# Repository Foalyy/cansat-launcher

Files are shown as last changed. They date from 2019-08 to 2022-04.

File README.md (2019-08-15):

# cansat-launcher



This repository provides the documentation (in French) and the CAD files.

Related repositories :
- Kicad project : https://github.com/Foalyy/cansat-launcher-kicad
- Main board firmware : https://github.com/Foalyy/cansat-launcher-firmware
- Remote control firmware : https://github.com/Foalyy/cansat-launcher-firmware-remote

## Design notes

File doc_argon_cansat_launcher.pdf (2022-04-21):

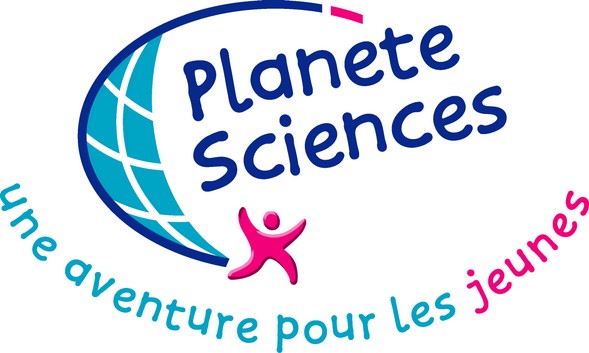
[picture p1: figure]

# Largueurs CanSat

# Argon

## Documentation

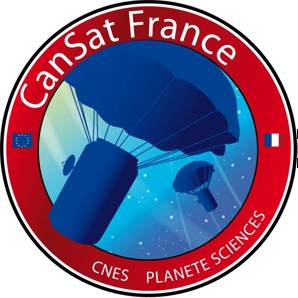
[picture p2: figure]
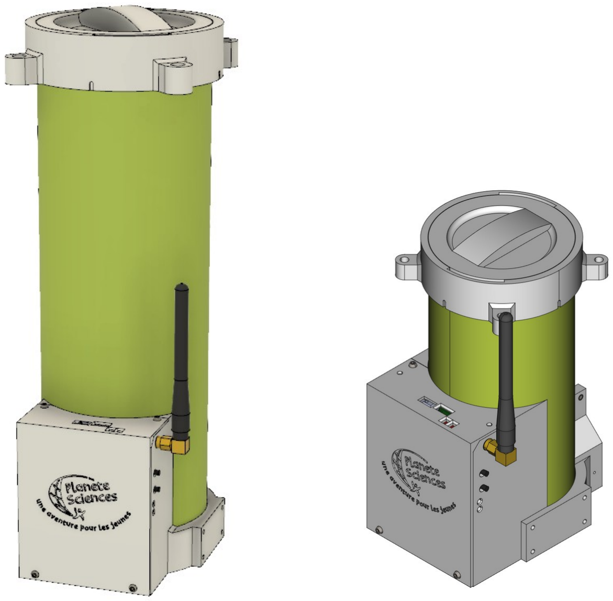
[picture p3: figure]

### Table des matières

## 1 – Manuel utilisateur

### 1.1 – Informations générales

Les largueurs existent en deux versions : la version originale « 1L » et la version « mini ».

Pour chaque version, trois largueurs sont disponibles, chacun ayant un numéro et une

couleur :

- 1 : vert
- 2 : rouge
- 3 : jaune

Deux télécommandes identiques permettent de commander à distance l’ouverture et la

fermeture (ou plus précisément, le verrouillage) de la trappe, et de recevoir des données

de télémétrie, en particulier l’altitude du largueur.

Dimensions de la version 1L :

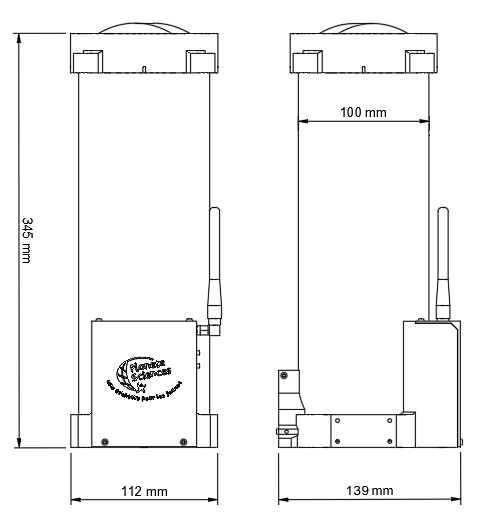
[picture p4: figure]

Masse à vide : environ 600g.

Dimensions de la version Mini :

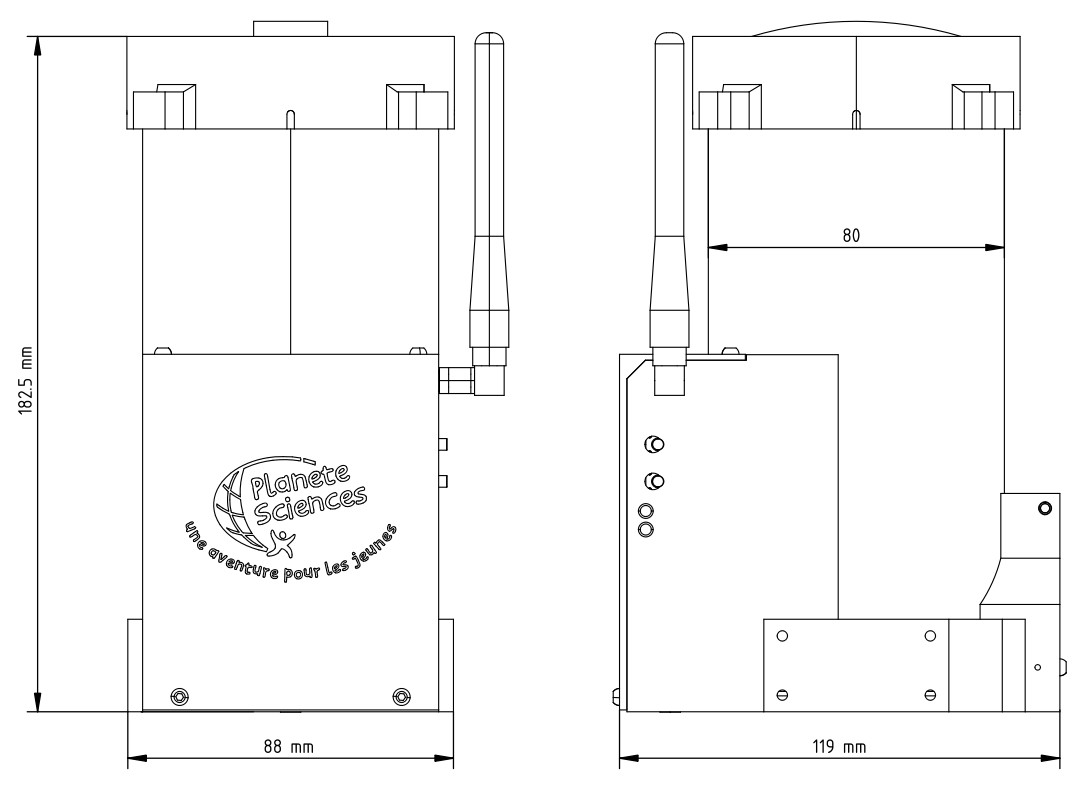
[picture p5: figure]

Masse à vide : environ 400g.

### 1.2 – Contenu des caisses

# Largueurs 1L

Deux caisses contiennent les largueurs et leurs accessoires.

La première caisse contient :

- Un largeur
- Les télécommandes
- La trousse d’accessoires contenant :
- Les trois antennes des largueurs
- Un chargeur secteur USB 3-ports
- Trois cables micro-USB
- Trois clés hexagonales 1.5mm
- Trois boîtes de rangement de batteries contenant chacun une batterie de

rechange (la deuxième batterie de chaque boîte restant dans le largueur)

- Quelques mousquetons de rechange
- Une copie de cette documentation

La deuxième caisse contient :

- Les deux autres largueurs

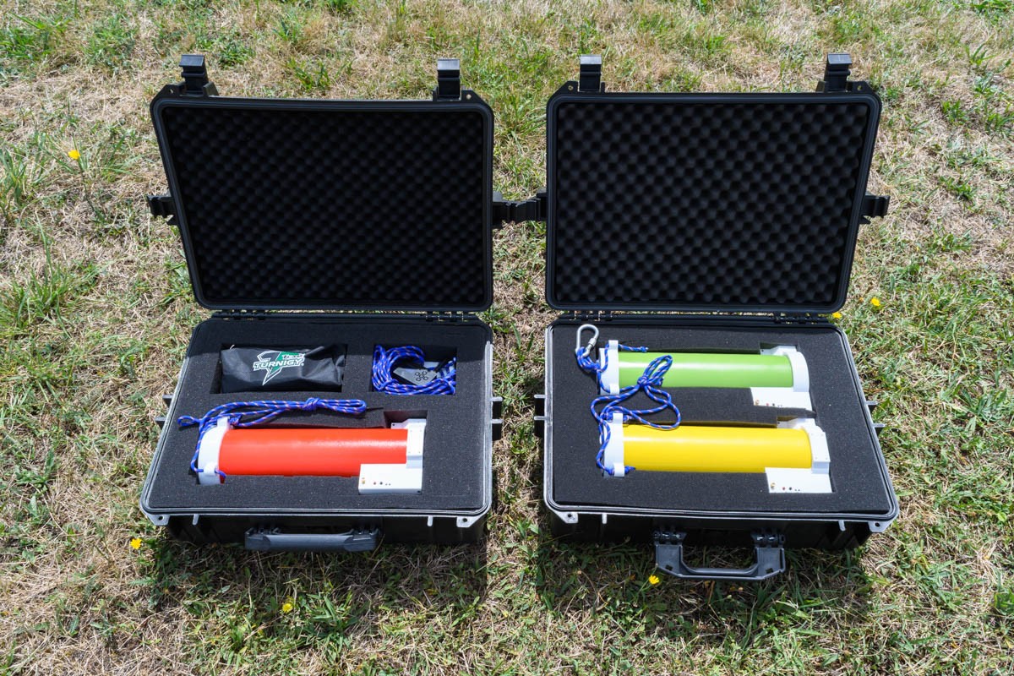
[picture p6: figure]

# Mini-largueurs

Les mini-largueurs sont stockés de manière similaire dans une unique caisse.

### 1.3 – Préparation en début de campagne

Pour chaque largueur :

1. Visser son antenne
2. Allumer le largueur et vérifier son fonctionnement manuel en testant le

mécanisme d’ouverture/fermeture à l’aide des boutons sur le côté. S’il ne s’allume

pas, la batterie doit être vide : brancher un cable USB pour l’allumer.

3. Enclencher le ressort :
1. Ouvrir la trappe avec le bouton noir

2. Dévisser la vis noire sous la charnière de la trappe à l’aide de l’une des clés

hexagonales dans la trousse à accessoires (voir photos plus bas)

3. Faire passer la boucle du ressort dans la vis puis la revisser
4. Refermer la trappe et la verrouiller avec le bouton rouge
5. Vérifier le bon fonctionnement du largueur à l’aide d’une télécommande

(ouverture, fermeture, télémétrie)

6. Recharger le largueur (prévoir environ 6 heures si la batterie est déchargée). Le

largueur doit être allumé pour pouvoir être rechargé.

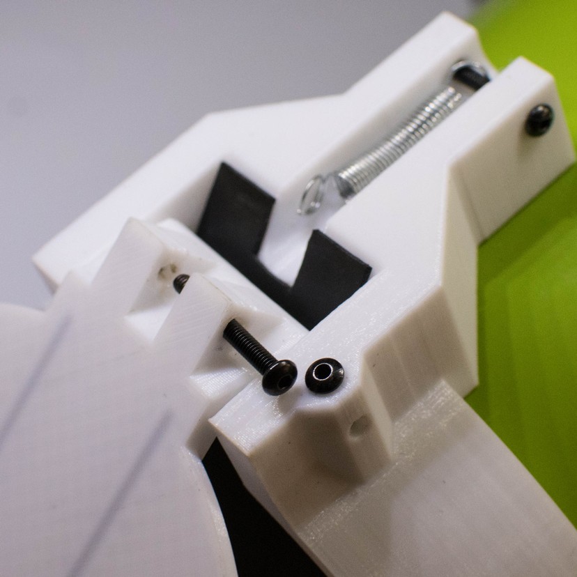
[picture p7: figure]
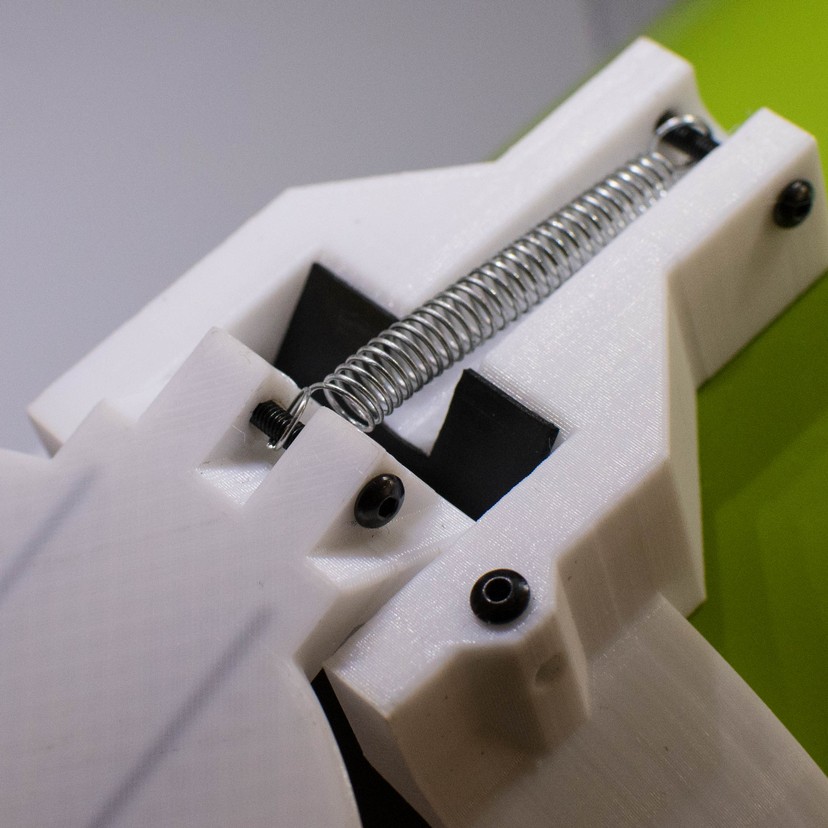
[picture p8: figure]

### 1.4 – Rangement en fin de campagne

Pour chaque largueur :

1. Regarder la charge de la batterie à l’aide d’une télécommande. Si la charge est

inférieure à 50 %, recharger le largueur jusqu’à environ 50 % (il n’est pas conseillé

de stocker la batterie pendant une longue durée complètement vide ni à pleine

charge).

2. Désenclencher le ressort de la trappe en suivant la même procédure que pour la

préparation en début de campagne (voir photos dans la section précédente) :

1. Allumer le largueur et ouvrir la trappe à l’aide du bouton
2. Dévisser la vis du bas pour dégager la boucle du ressort
3. Revisser la vis
4. Fermer et verrouiller la trappe à l’aide du bouton rouge
3. Dévisser l’antenne et la ranger dans la trousse d’accessoires
4. Ranger le largueur dans la caisse

Avant de fermer les caisses, vérifier l’inventaire (notamment de la trousse d’accessoires)

à l’aide de la liste à la section 1.2.

## 2 – Manuel technique

Ce chapitre détaille la conception du largueur et a pour but de servir de référence pour

comprendre, réparer ou construire de nouveaux largueurs.

Les fichiers STEP/STL et Gcode des pièces fabriquées par impression 3D, les plans des

cartes électroniques, ainsi que les codes sources des firmwares embarqués dans les

largueurs et les télécommandes, sont disponibles sous licence GPL sur Github :

https://github.com/Foalyy/cansat-launcher

Un build log est également disponible :

https://silica.io/argon-remote-controlled-launchers-for-the-cansat-competition/

### 2.1 – Mécanique

2.1.1 – Construction générale

Les largueurs sont construits sur la base d’un tube PVC standard du commerce, de

pièces fabriquées par impression 3D, et de divers composants dont la liste est détaillée

plus loin. Les images montrent les largueurs 1L ; la construction des mini-largueurs est

similaire, à l’exception du tube PVC qui est de diamètre 80mm (100mm pour les

largueurs 1L) et des pièces imprimées 3D dont la géométrie est adaptée en

conséquence. Les fichiers 3D des deux versions sont disponibles sur GitHub.

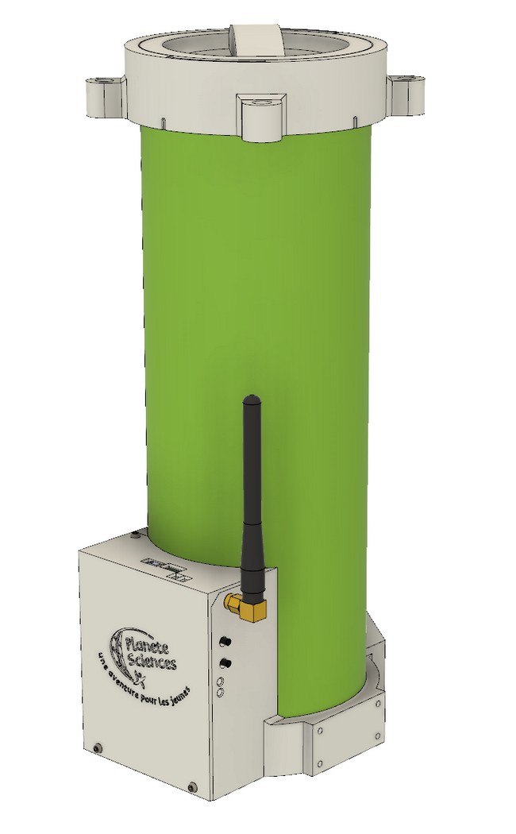
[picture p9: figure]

2.1.2 – Impression 3D

Toutes les pièces sont imprimées avec du filament Polymaker PC-Max blanc sur une

Ultimaker 2+ avec Simplify3D. Le choix s’est porté sur le polycarbonate pour sa

robustesse et sa haute tenue en température afin qu’il garde sa rigidité même pendant

de longues heures en plein soleil.

Les anneaux haut et bas sont ajustés pour rentrer « en force » autour du tube. Si besoin,

ils peuvent être collés. Il n’a pas été prévu de vis afin de laisser l’intérieur du tube

complètement lisse et éviter les risques d’accrochage des parachutes des CanSats.

Les autres pièces sont fixées à l’aide de vis et d’inserts M2.5 mis en place à chaud avec

un fer à souder.

De chaque côté du largueur, une plaque et 4 inserts permettent de fixer des

accessoires : caméra, capteurs annexes, …

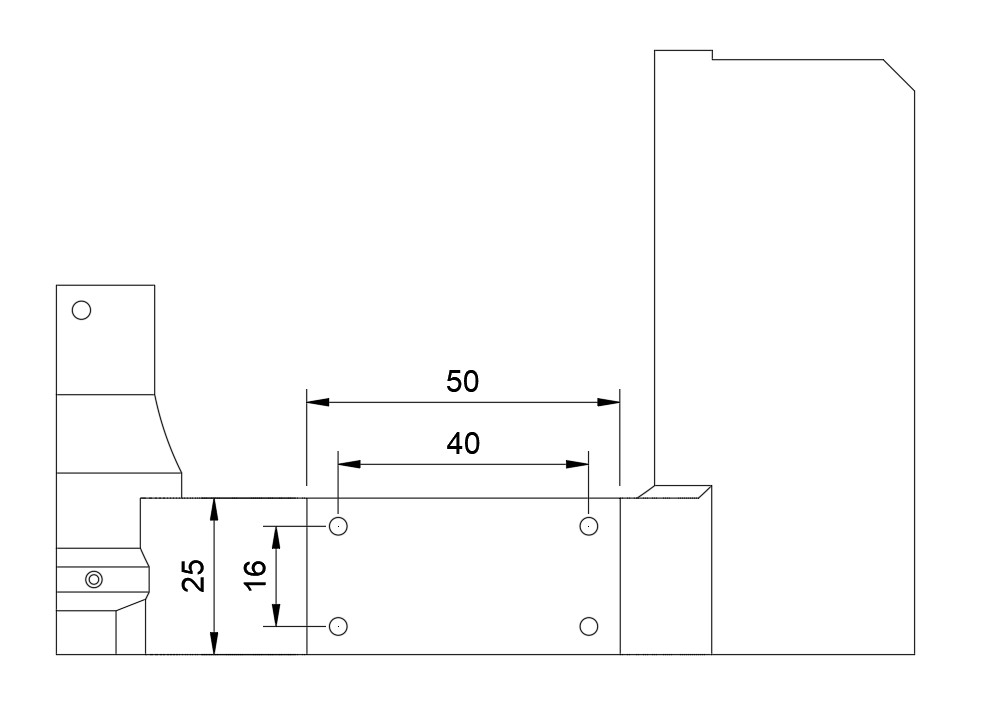
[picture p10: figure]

Caractéristiques principales du profil d’impression utilisé :

- hauteur de couche : 0.2mm
- nombre de couches externes : 2 ou 3 suivant les pièces
- remplissage : 15 à 25 % suivant les pièces
- température : extrudeur 265°C, plateau 115°C
- ventilateurs : 80 %
- vitesse : 2000mm/min
- enceinte d’impression fermée par un drap

Liste des pièces :

- Anneau bas : pièce principale intégrant le bloc électronique (dont servo et

batterie) et la charnière de la trappe. Impression avec 3 couches pour favoriser la

solidité de la pièce et la tenue des inserts. Nécessite des supports.

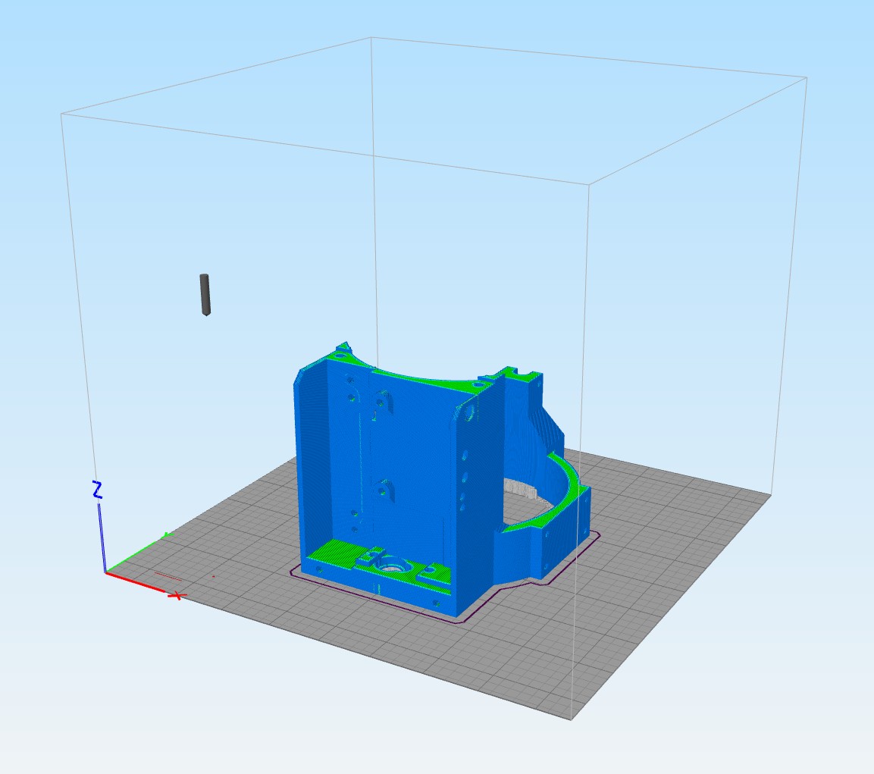
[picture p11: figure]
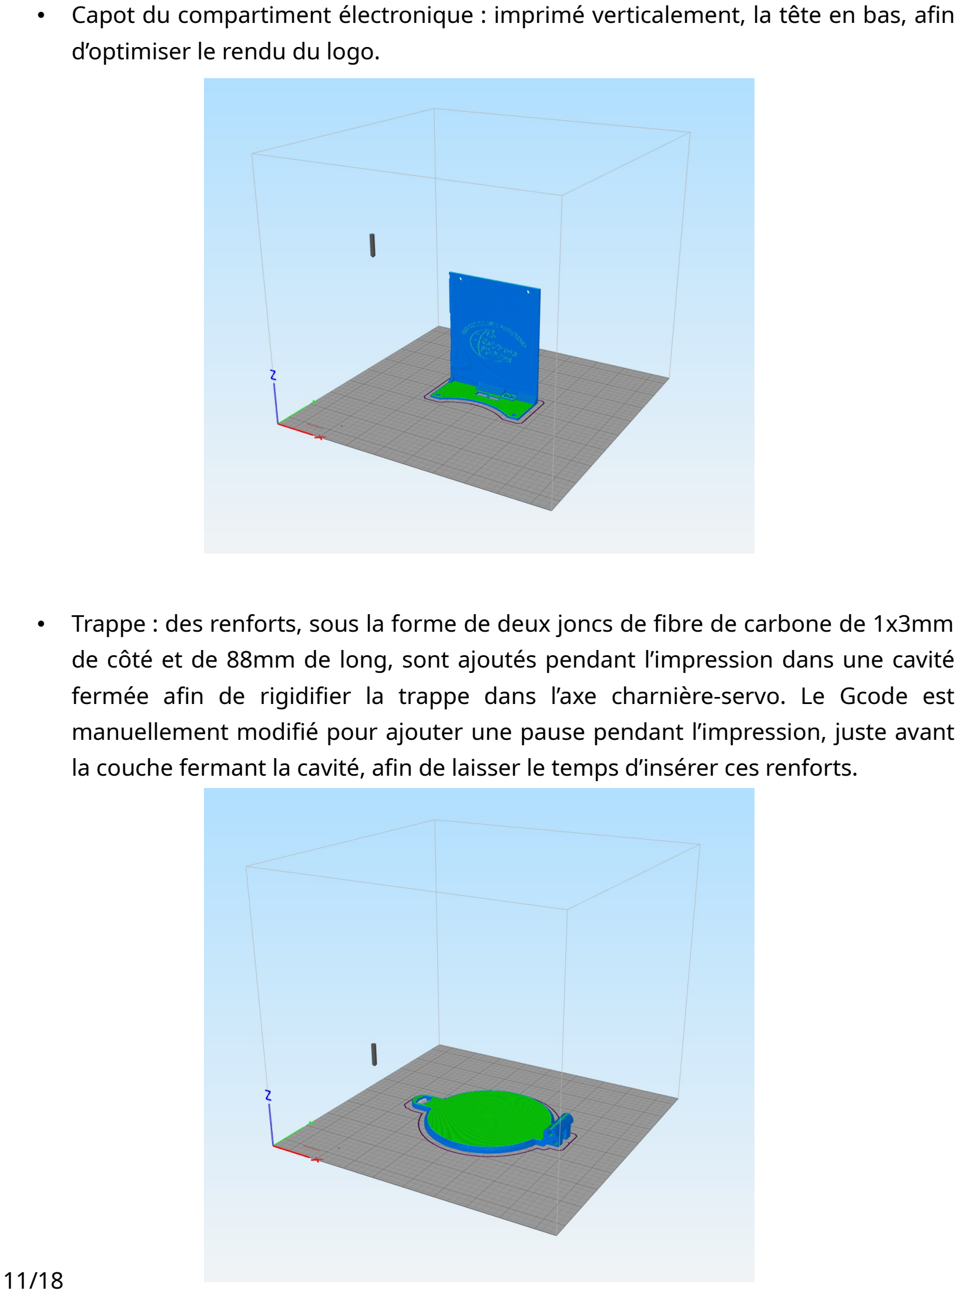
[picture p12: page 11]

- Capot du compartiment électronique : imprimé verticalement, la tête en bas, afin

d’optimiser le rendu du logo.

- Trappe : des renforts, sous la forme de deux joncs de fibre de carbone de 1x3mm

de côté et de 88mm de long, sont ajoutés pendant l’impression dans une cavité

fermée afin de rigidifier la trappe dans l’axe charnière-servo. Le Gcode est

manuellement modifié pour ajouter une pause pendant l’impression, juste avant

la couche fermant la cavité, afin de laisser le temps d’insérer ces renforts.

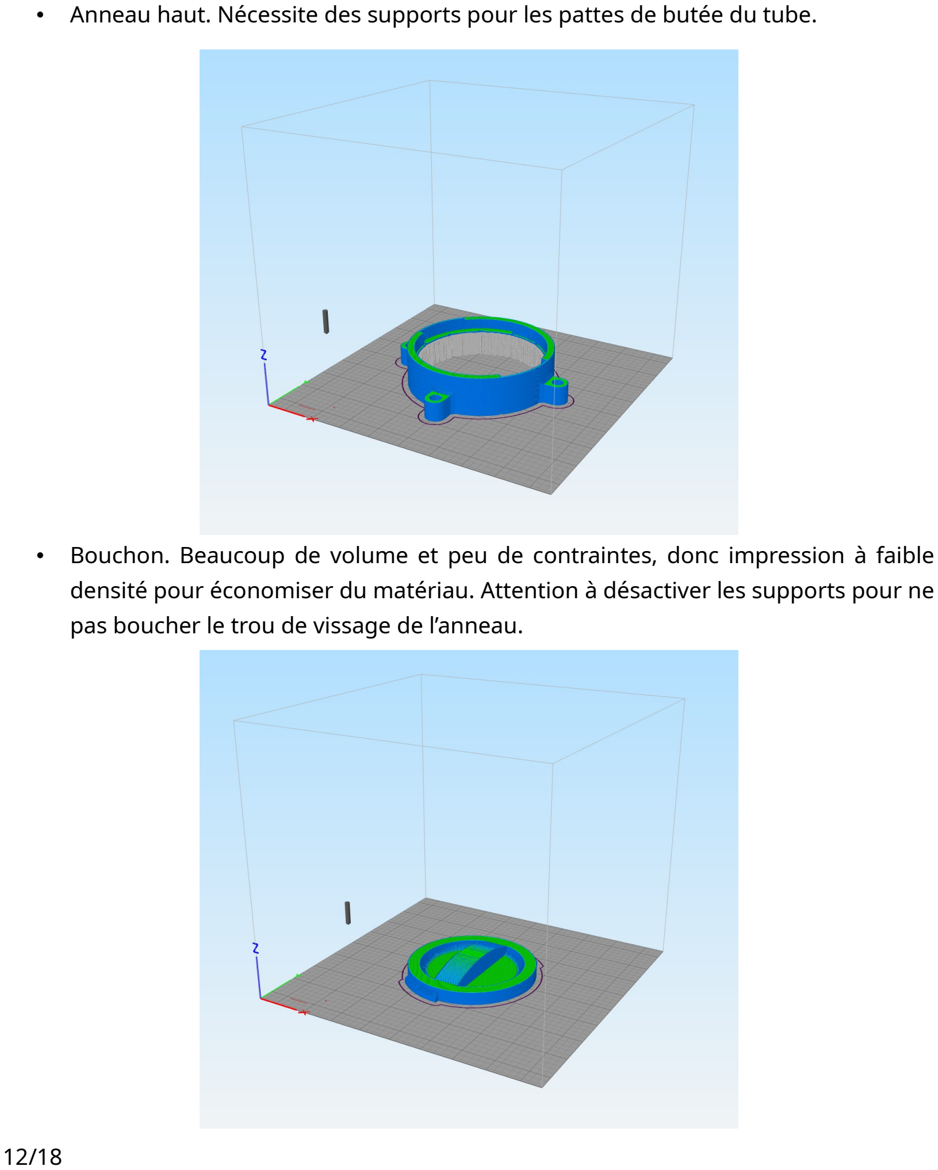
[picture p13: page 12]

- Anneau haut. Nécessite des supports pour les pattes de butée du tube.
- Bouchon. Beaucoup de volume et peu de contraintes, donc impression à faible

densité pour économiser du matériau. Attention à désactiver les supports pour ne

pas boucher le trou de vissage de l’anneau.

2.1.3 – Listes des pièces du commerce

- Tube : tube PVC standard 100mm, découpé à 33cm afin de construire 3 largueurs

dans 1m de tube

https://www.leroymerlin.fr/v3/p/produits/tube-d-evacuation-pvc-diam-100-mm-l-

1-m-e9941 (https://www.leroymerlin.fr/v3/p/produits/tube-d-evacuation-pvc-diam-100-mm-l-1-m-e9941)

- Vis : M2.5, tête bouton hexagonale, en longueur 6, 10 et 20mm

https://www.aliexpress.com/item/32965979997.html

- Inserts : M2.5, 4mm

https://www.aliexpress.com/item/32879217592.html

- Axes des charnières : axe acier 2x40mm

https://www.aliexpress.com/item/32967805012.html

- Guides des charnières (côté trappe) : tube Teflon ID3mm OD4mm, découpé à

30mm

https://www.aliexpress.com/item/32730855848.html

- Ressorts : 7.9x28.5mm

https://www.aliexpress.com/item/32947857101.html

- Crochets sur les bouchons : 11x22mm

https://www.aliexpress.com/item/32544549680.html

- Mousquetons sur les crochets

https://www.aliexpress.com/item/32961944039.html

- Corde 5mm pour la fixation au ballon

https://www.leroymerlin.fr/v3/p/produits/corde-polypropylene-tressee-standers-

diam-5-mm-x-l-15-m-e1401433358 (https://www.leroymerlin.fr/v3/p/produits/corde-polypropylene-tressee-standers-diam-5-mm-x-l-15-m-e1401433358)

### 2.2 – Électronique

2.2.1 – Description générale

L’électronique est composée d’un unique PCB intégrant la gestion d’énergie, le

microcontrôleur principal, le module LoRa, et les diverses connectiques nécessaires.

La carte inclus notamment les fonctionnalités suivantes :

- protection anti inversion de polarité
- protection anti sous-tension de batterie (coupure à 3V)
- recharge de la batterie par le port micro-USB (profil CC-CV, ~400mA et 4.2V) avec

indication d’état par LEDs

- step-up 5V pour l’alimentation du servo
- microcontrôleur ATSAM4LS2B
- module radio LoRa RMF96W à 868MHz
- altimètre basé sur le capteur de pression/température BMP388
- switches de configuration
- boutons d’ouverture/fermeture manuelle de la trappe
- LEDs indiquant l’état de la trappe et l’activité sur le transmetteur
- connecteur auxiliaire I2C permettant de brancher un capteur
- connecteur auxiliaire disposant de 2 entrées/sorties génériques reliées au

microcontrôleur.

Les switches de configuration permettent de définir l’adresse de chaque largueur.

Chaque switch code un bit d’adresse, valant 0 (switch en bas) ou 1 (switch en haut). Le

largueur vert a l’adresse 0 (0000), le rouge l’adresse 1 (0001) et le jaune l’adresse 2

(0010).

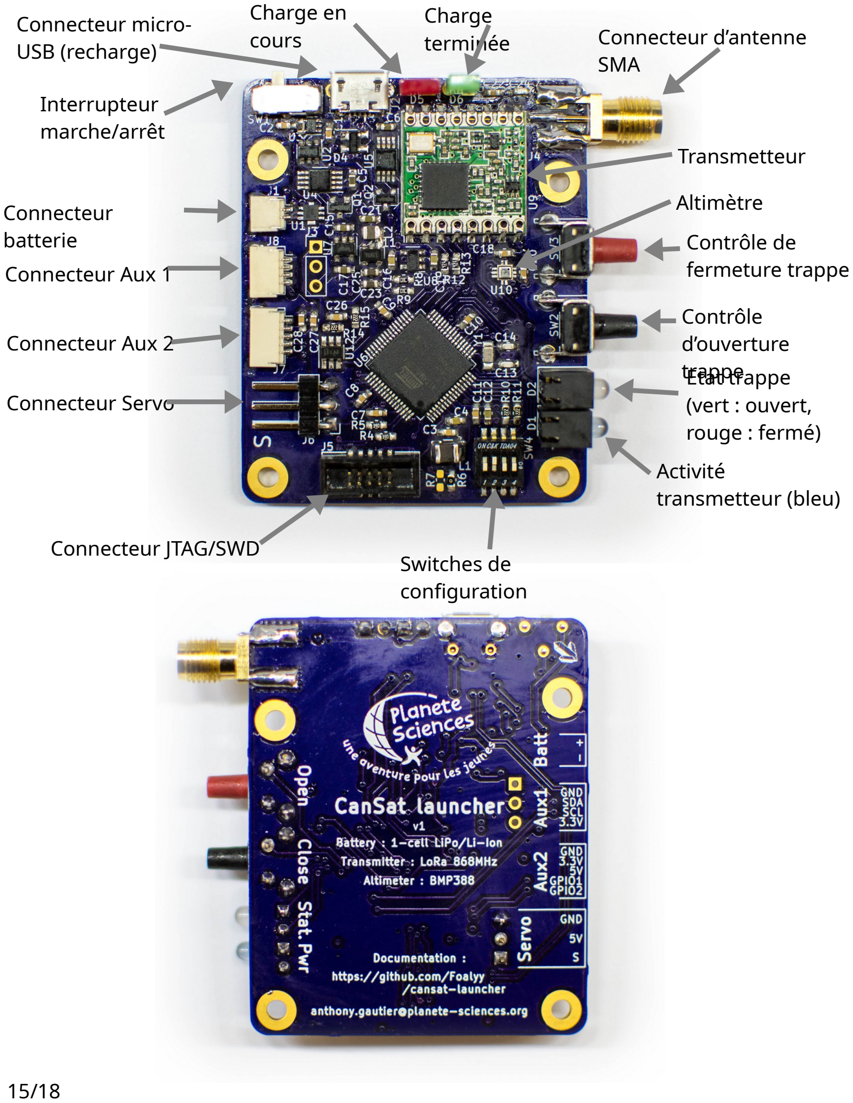
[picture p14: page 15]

Transmetteur

Connecteur d’antenne

SMA

Charge

terminée

Charge en

cours

Interrupteur

marche/arrêt

Connecteur

batterie

Connecteur Aux 1

Connecteur Aux 2

Connecteur Servo

Connecteur JTAG/SWD | Switches de
| configuration

Contrôle de

fermeture trappe

Contrôle

d’ouverture

trappe Etat trappe

(vert : ouvert,

rouge : fermé)

Activité

transmetteur (bleu)

Altimètre

Connecteur micro-

USB (recharge)

2.2.2 – Pinout des connecteurs

Connecteur batterie :

+

Connecteur Aux 1 : peut servir à brancher un capteur auxiliaire en I2C à 3.3V

GND

SDA

SCL

3V3

Connecteur Aux 2 : permet de brancher un périphérique auxiliaire à 3.3V ou 5V avec

deux entrées/sorties génériques

GND

3V3

5V

GPIO1

GPIO2

Connecteur Servo :

GND

5V

PWM

Connecteur JTAG/SWD :

TMS TCK TDO TDI RST

JST-SH-2

JST-SH-4

JST-SH-5

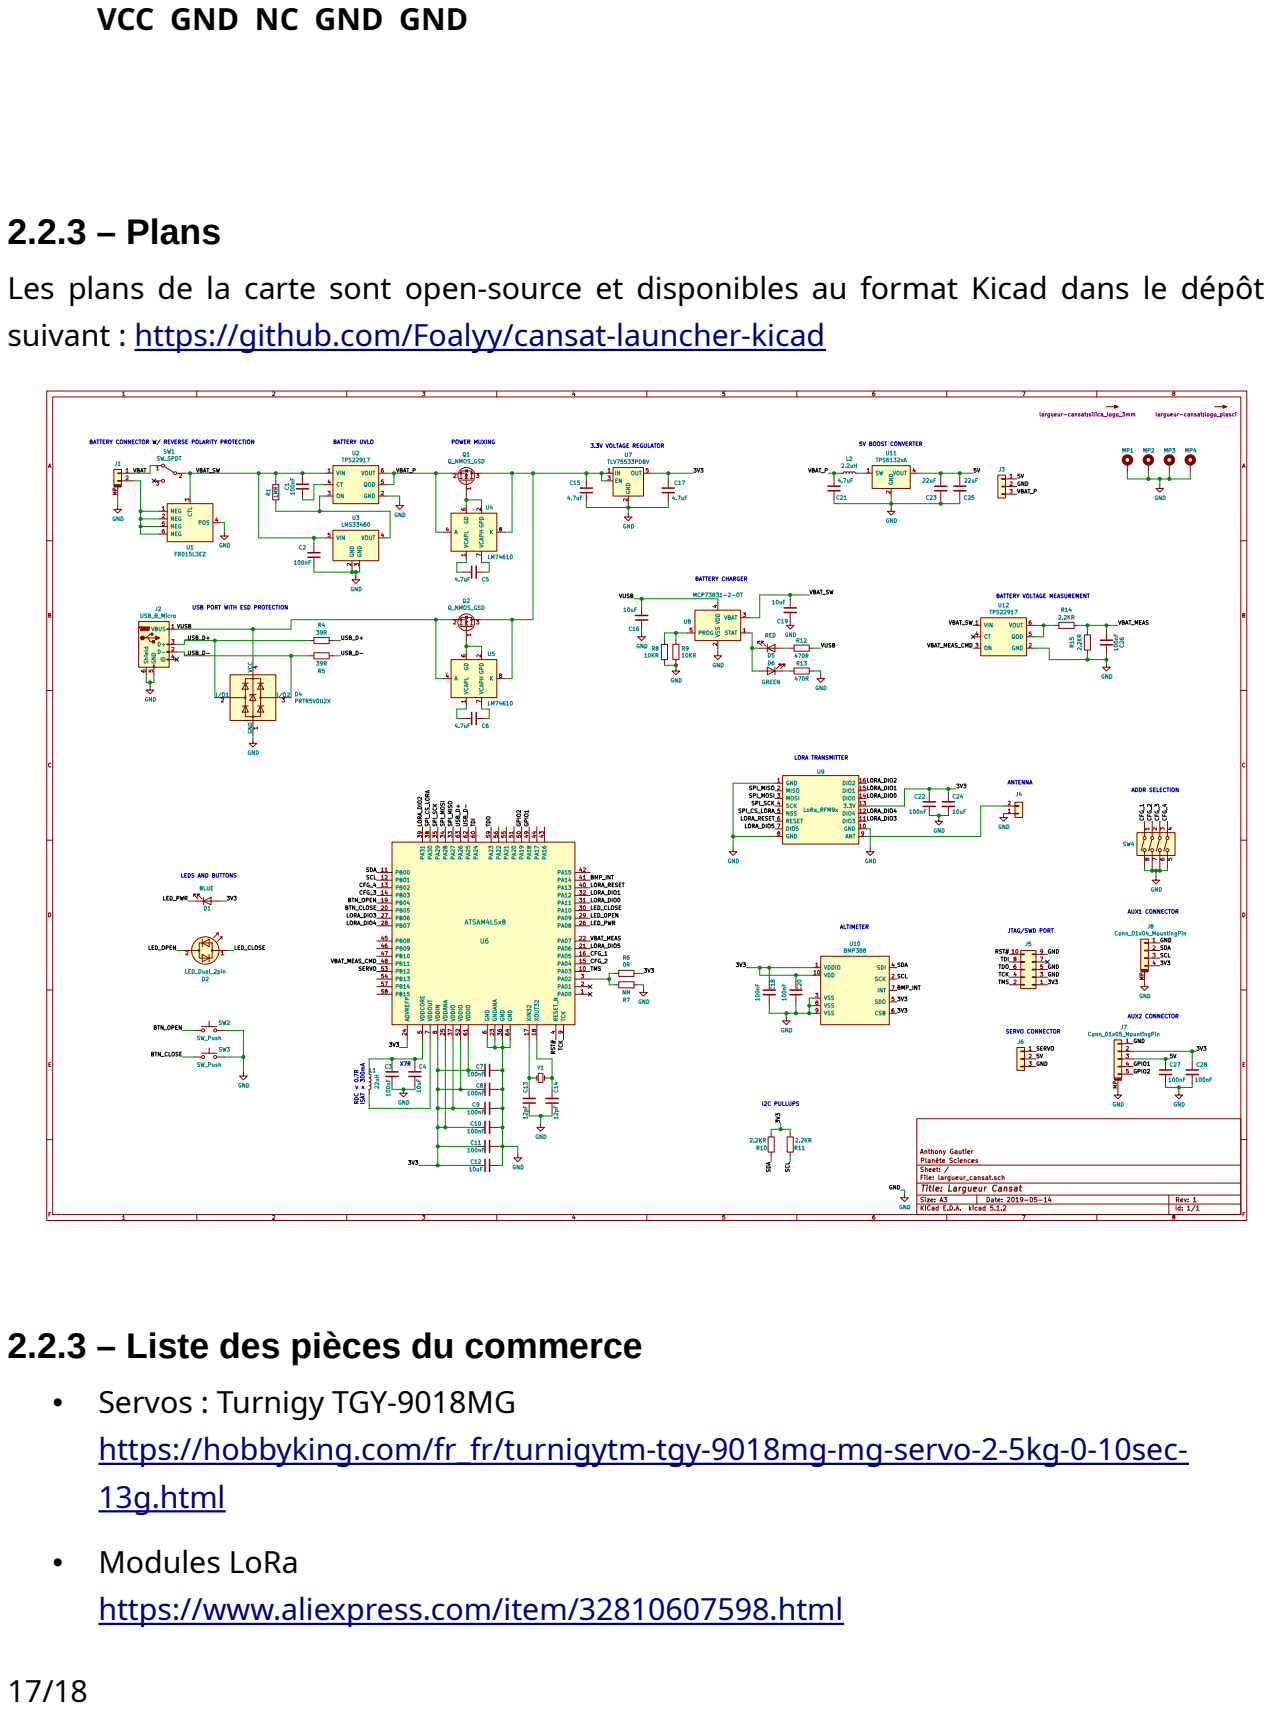
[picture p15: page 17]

VCC GND NC GND GND

Les plans de la carte sont open-source et disponibles au format Kicad dans le dépôt

suivant : https://github.com/Foalyy/cansat-launcher-kicad

BATTERY CONNECTOR W/ REVERSE POLARITY PROTECTION

JTAG/SWD PORT BATTERY VOLTAGE MEASUREMENT

3V3 USB PORT WITH ESD PROTECTION

3 POS 4 NEG 5 NEG 6 U1 FR015L3EZ GND

File: largueur_cansat.sch Sheet: / Planète Sciences

Id: 1/1 Title: Largueur Cansat

2.2.3 – Liste des pièces du commerce

https://hobbyking.com/fr_fr/turnigytm-tgy-9018mg-mg-servo-2-5kg-0-10sec-

https://www.aliexpress.com/item/32810607598.html

- Logements batterie

https://www.aliexpress.com/item/32831018807.html

- Boites batteries

https://www.aliexpress.com/item/32814221499.html

- Antennes 868MHz

https://www.aliexpress.com/item/32964912902.html

- Cables USB

https://www.aliexpress.com/item/32996600477.html

- Chargeur USB

https://www.aliexpress.com/item/32914344898.html

### 2.3 – Firmware

Les firmwares des microcontrôleurs ATSAM4L sont basés sur la bibliothèque

libtungsten : https://libtungsten.io/.

2.3.1 – Largueurs

Le | code | source | est | open-source | et | disponible | dans | le | dépôt | Github :

https://github.com/Foalyy/cansat-launcher-firmware

2.3.2 – Télécommandes

Les télécommandes des largueurs sont basées sur l’électronique des télécommandes

d’appareil photo open-source Silver : https://silica.io/silver-an-open-source-long-range-

camera-remote-control/ (https://silica.io/silver-an-open-source-long-range-camera-remote-control/)

Le code source spécifique aux largueurs est disponible dans le dépôt Github :

https://github.com/Foalyy/cansat-launcher-firmware-remote

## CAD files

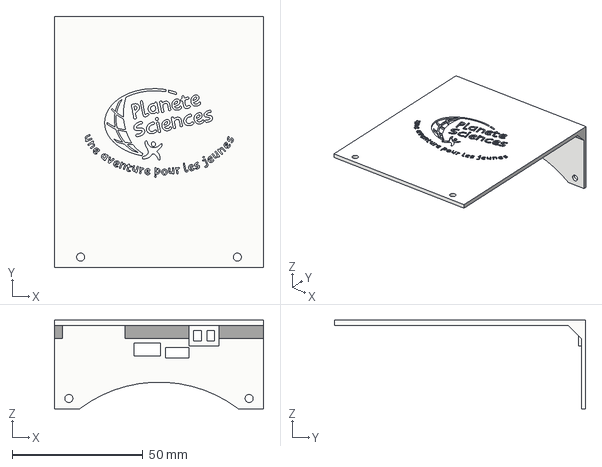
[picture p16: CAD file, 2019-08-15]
cad/1L/step/elec_cover.step
80.0 x 96.1 x 34.0 mm

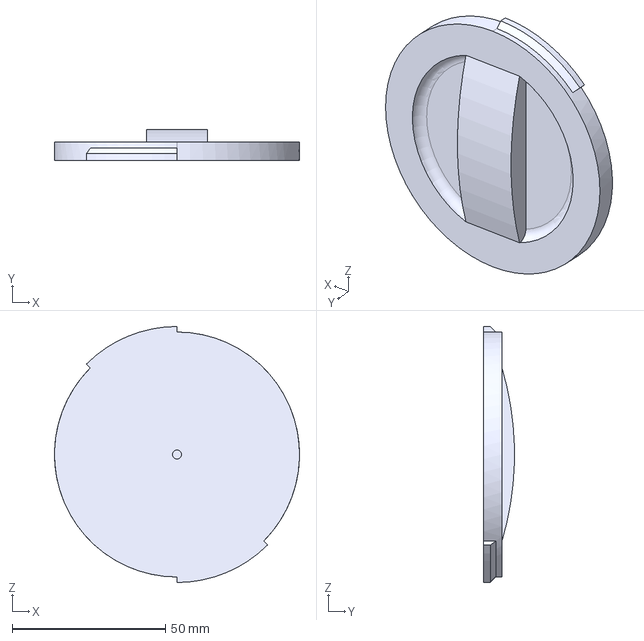
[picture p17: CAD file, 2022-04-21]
cad/mini/step/lid.step
80.0 x 10.0 x 83.6 mm

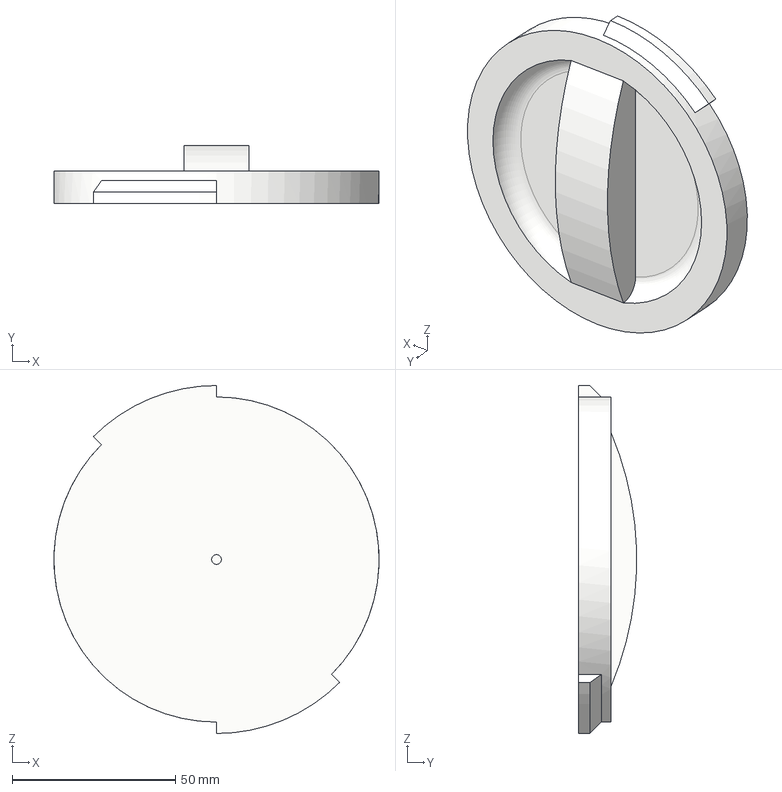
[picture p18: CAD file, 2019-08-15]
cad/1L/step/lid.step
99.4 x 17.7 x 106.5 mm

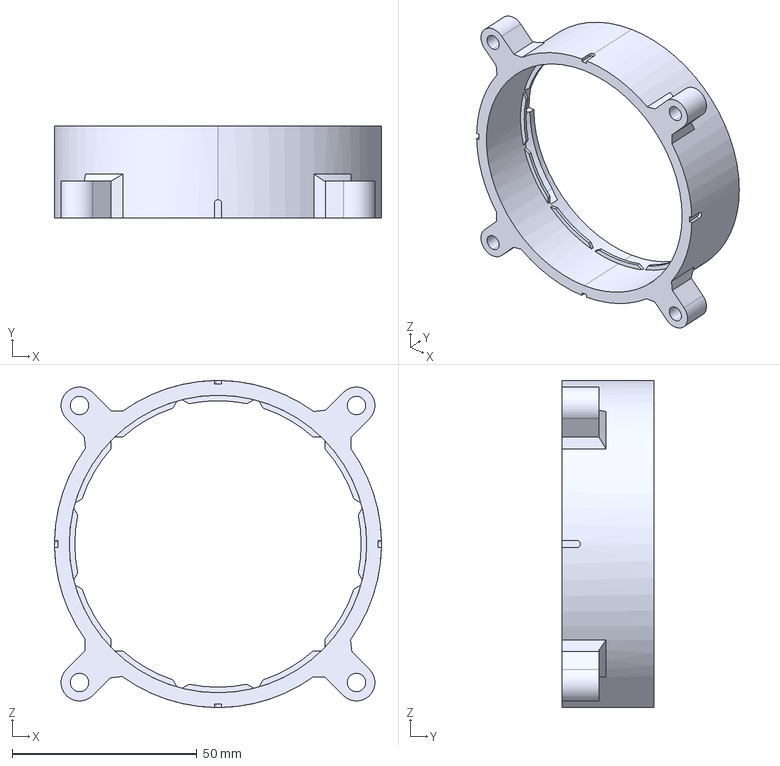
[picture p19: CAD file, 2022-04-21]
cad/mini/step/top_ring.step
88.5 x 25.0 x 88.5 mm

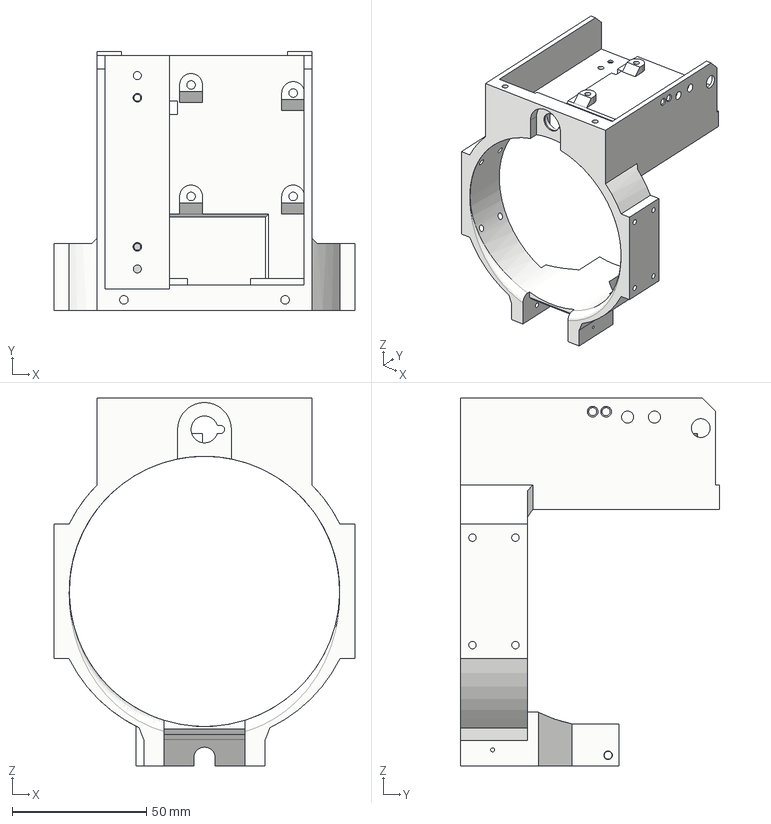
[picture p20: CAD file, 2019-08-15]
cad/1L/step/bottom_ring.step
112.0 x 96.5 x 137.0 mm

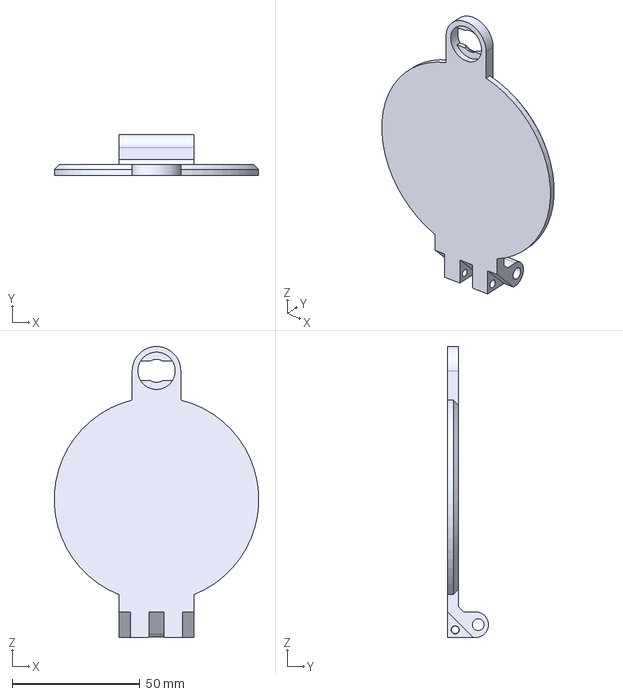
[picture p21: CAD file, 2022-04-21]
cad/mini/step/hatch.step
79.9 x 16.0 x 113.8 mm

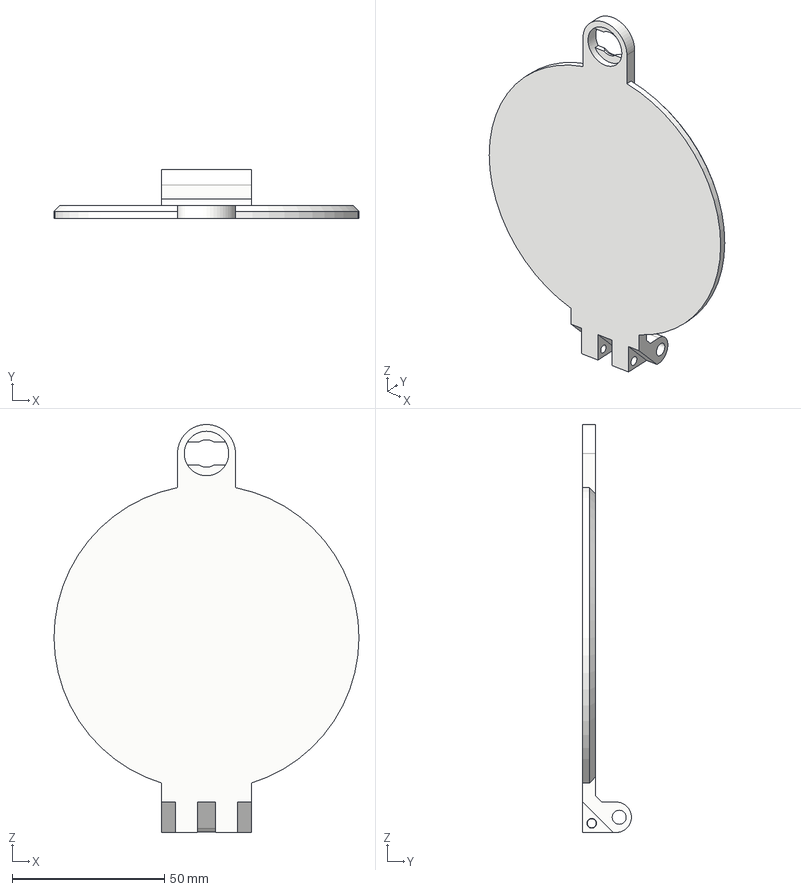
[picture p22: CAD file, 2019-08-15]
cad/1L/step/hatch.step
100.0 x 16.0 x 133.8 mm

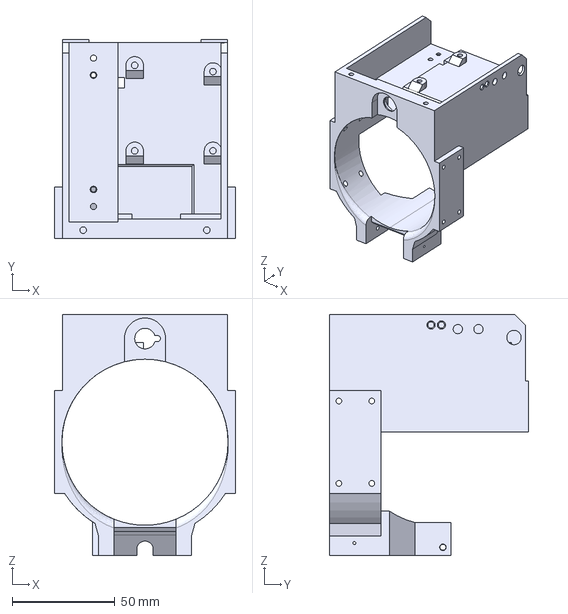
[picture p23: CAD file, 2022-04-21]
cad/mini/step/bottom_ring.step
88.0 x 96.5 x 117.0 mm

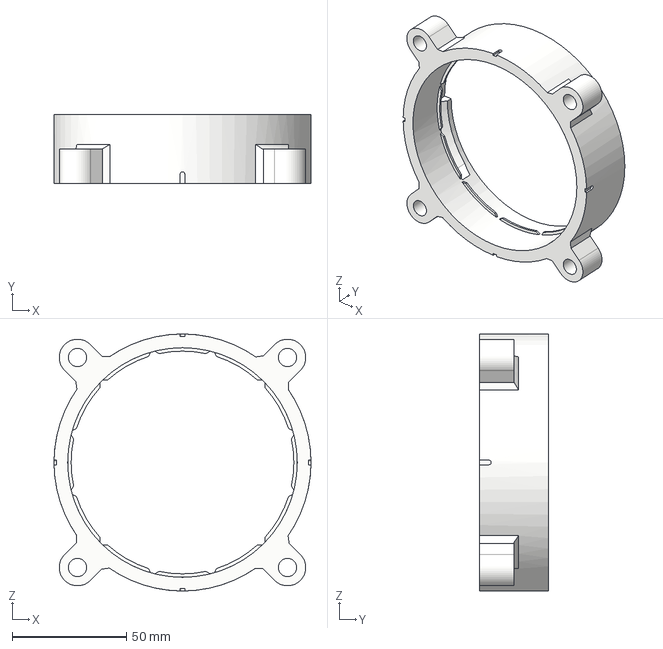
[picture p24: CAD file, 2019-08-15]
cad/1L/step/top_ring.step
112.5 x 30.0 x 112.5 mm

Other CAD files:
cad/mini/step/elec_cover.step
cad/1L/stl/bottom_ring.stl
cad/1L/stl/elec_cover.stl
cad/1L/stl/hatch.stl
cad/1L/stl/lid.stl
cad/1L/stl/top_ring.stl
cad/mini/stl/bottom_ring.stl
cad/mini/stl/elec_cover.stl
cad/mini/stl/hatch.stl
cad/mini/stl/lid.stl
cad/mini/stl/top_ring.stl

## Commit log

2019-08-15 Added doc and CAD files
    [bottom_ring.step, bottom_ring.stl, elec_cover.step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]
2022-04-21 Added CAD files for Mini model
    [bottom_ring.step, bottom_ring.stl, elec_cover.step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]
